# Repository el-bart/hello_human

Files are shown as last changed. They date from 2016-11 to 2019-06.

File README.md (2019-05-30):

# hello human

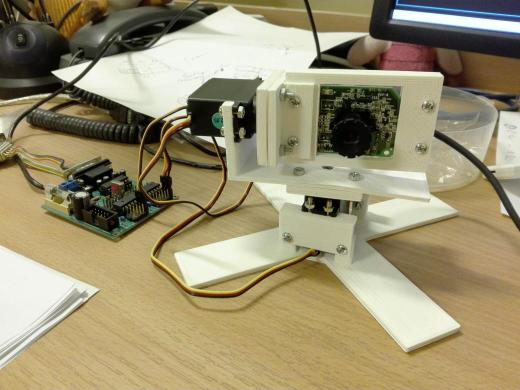
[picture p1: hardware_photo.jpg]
hardware construct


small hackaton to show ppl what programming is... doing stuff in real life. :)
it's more about the end effect than the code (quality) itself.

project is about making a 3d-printed box for usb-cam, that tracks faces it sees.

project is a mixture of Python and OpenSCAD code.

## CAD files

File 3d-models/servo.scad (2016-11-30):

use <servoMountLock.scad>

module servo()
{
  cube([40, 20, 36]);
  // mount shelf
  difference()
  {
    translate([-13/2, 0, 26])
      cube([53, 20, 3]);
    // holes
    #for(dx=[-1, +1])
      for(dy=[-1, +1])
        translate([53/2-13/2+dx*47/2, 20/2+dy*(6-1), 26-4])
          cylinder(r=4/2, $fs=1, h=10);
  }
  // rotor bottom
  translate([13/2+3.5, 20/2, 36])
  {
    cylinder(r=13/2, h=2);
    // rotor itself
    translate([0,0,2])
    {
      cylinder(r=9/2, h=2.5);
      // center part
      translate([-10/2, -10/2, 2.5])
      {
        cube([10, 10, 3.2]);
        // side bars
        translate([-10, (10-7.2)/2, 1.2])
          cube([30, 7.2, 2]);
      }
    }
  }
}

servo();

%translate([13/2+3.5, 20/2, 36+3.2-0.5])
  rotate([0, 0, 90])
    servoMountLock();

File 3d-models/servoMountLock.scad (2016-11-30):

module servoMountLock()
{
  space=[0.5, 0.5, 0.5];
  difference()
  {
    translate([-14-5, -10-10, 0])
      cube([2*(14+5), 2*(10+10), 4.5]);
    // screw holes
    for(dx = [-1, +1])
      for(dy = [-1, +1])
        translate([dx*14, dy*10, -2])
          cylinder(r=(3+1)/2, $fs=1.5, h=4.5+4);
    translate([0, 0, 1])
    {
      // main rod mounting hole
      translate([-(7.5+space[0])/2, -(30+space[1])/2, 4.5-(2+space[2])])
        cube([7.5, 30, 2] + space);
      // center, thicker part
      translate([-(10+space[0])/2, -(10+space[1])/2, 4.5-(3.5+space[2])])
        cube([10, 10, 3.5] + space);
    }
    // servo's screw space
    translate([0, 0, -1])
      cylinder(r=(9+1)/2, h=6, $fs=1);
  }
}

for(i=[0:1])
  translate([0, i*45, 0])
    servoMountLock();

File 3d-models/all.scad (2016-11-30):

use <bottomMount.scad>
use <servoMountLock.scad>
use <tiltMountBase.scad>
use <cameraFrame.scad>

use <servo.scad>
use <cammera.scad>


for(dy=[0,45])
  translate([0, dy, 0])
    servoMountLock();

translate([0, -45, 0])
  tiltMountBase();

translate([-73, -52, 0])
  rotate([0, 0, 180])
    bottomMount();

for(dy=[0, 50])
  translate([-95, -30+dy, 0])
    cameraFrame();


%translate([0, 100, 0])
{
  bottomMount();

  translate([-71, -13.5, 21])
  {
    rotate([0,90,0])
      rotate([0,0,90])
      {
        servo();
        translate([13/2+3.5, 20/2, 36+3.2-0.5])
          rotate([0, 0, 90])
            servoMountLock();
      }
    translate([50, 10, -7])
    {
      translate([13, 0, 0])
        cammera();
      translate([-1, 2, -6])
        rotate([90, 0, 0])
          cameraFrame();
      translate([70-1, -5, -6])
        rotate([90, 0, 180])
          cameraFrame();
    }
    translate([44, 10, 10])
      rotate([0, 90, 0])
        tiltMountBase();
  }

  translate([10, -10, -44])
    rotate([0,0,90])
    {
      servo();
      translate([13/2+3.5, 20/2, 36+3.2-0.5])
        rotate([0, 0, 90])
          servoMountLock();
    }
}

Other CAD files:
3d-models/base.scad
3d-models/bottomMount.scad
3d-models/cameraFrame.scad
3d-models/cammera.scad
3d-models/tiltMountBase.scad

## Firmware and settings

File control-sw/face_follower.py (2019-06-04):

#!/usr/bin/env python
import sys
import cv2
import time
import getopt
import Servo
import Tracker


def parseCmdLine():
    opts, args = getopt.getopt(sys.argv[1:], "hpns:v:", ["help", "preview", "no-preview", "serial=", "video="])
    if len(args) > 0:
        raise Exception("unknown argument: '" + args[0] + "'")
    preview = None
    serialDevice = None
    videoDevice = None
    for opt, arg in opts:
        if opt == "-h" or opt == "--help":
            sys.stdout.write(sys.argv[0] + " --video /dev/videoX --serial /dev/ttyUSBY {--help|--preview|--no-preview}\n")
            sys.exit(0)
        if opt == "-p" or opt == "--preview":
            preview = True
            continue
        if opt == "-n" or opt == "--no-preview":
            preview = False
            continue
        if opt == "-s" or opt == "--serial":
            serialDevice = arg
            continue
        if opt == "-v" or opt == "--video":
            videoDevice = arg
            continue
    if preview is None:
        raise Exception("preview must be explicitly enabled or disabled")
    if serialDevice is None:
        raise Exception("serial device name must be xplicitly provided")
    if videoDevice is None:
        raise Exception("video device name must be xplicitly provided")
    return preview, serialDevice, videoDevice


def drawRectangles(faces, img):
    for (x,y,w,h) in faces:
        cv2.rectangle(img, (x,y), (x+w,y+h), (0,0xff,0), 6)

def imageCenter(img):
    h,w,channels = img.shape
    return (w/2, h/2)

previewWindow, serialDevice, videoDevice = parseCmdLine()

lineDrv = Servo.LineDriver(serialDevice)
position = Servo.Position(lineDrv, 'l', 'f')
tracker = Tracker.Tracker(position)
fullscreen = False


faceDetector = cv2.CascadeClassifier('haarcascade_frontalface_default.xml')
frameGrabber = cv2.VideoCapture( int(videoDevice[-1]) )

if previewWindow:
    if fullscreen:
        cv2.namedWindow("preview", cv2.WND_PROP_FULLSCREEN)
        cv2.setWindowProperty("preview", cv2.WND_PROP_FULLSCREEN, cv2.cv.CV_WINDOW_FULLSCREEN)
    else:
        cv2.namedWindow("preview", cv2.WINDOW_NORMAL)

ret    = 0
errors = 0
frameCount = 0
lastFpsPrint = time.time();

while True:
    try:
        frameCount += 1
        if frameCount > 20:
            now = time.time()
            timeElapsed = now - lastFpsPrint
            sys.stderr.write('\nFPS=' + str(frameCount / float(timeElapsed)) + '\n')
            frameCount = 0
            lastFpsPrint = now

        if cv2.waitKey(1) & 0xFF == ord('q'):
            break

        ret, img = frameGrabber.read()
        gray     = cv2.cvtColor(img, cv2.COLOR_BGR2GRAY)
        center   = imageCenter(img)
        faces    = faceDetector.detectMultiScale(gray, 1.3, 5)
        if previewWindow:
            drawRectangles(faces, img)
            cv2.imshow("preview",img)

        tracker.updatePositionForFaces(faces, center)
        sys.stderr.write('#')
        errors = 0

    except Exception as ex:
        errors += 1
        sys.stderr.write('!')
        sys.stderr.write( "\n" + sys.argv[0] + ": ERROR: " + str(ex) + "\n" )
        if errors > 20:
            sys.stderr.write("\n" + sys.argv[0] + ": TOO MANY ERRORS IN A ROW - SHUTTING DOWN...\n")
            ret = 42
            break

sys.stderr.write('\n')
frameGrabber.release()
cv2.destroyAllWindows()
sys.exit(ret)

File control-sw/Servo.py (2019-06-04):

#!/usr/bin/env python
import time
import serial


class LineDriver:
    def __init__(self, dev, timeout = 0.050):
        self._io = serial.Serial(port=dev, baudrate=38400, timeout=0)
        if not self._io.isOpen():
            raise Expception("cannot open serial port: " + dev)
        self._timeout = timeout

    def sendCmd(self, cmd):
        self._io.write(cmd + "\n")

    def readResponse(self):
        return self.__readLine()

    def __readLine(self):
        deadline = time.time() + self._timeout
        line = ''
        while time.time() <= deadline:
            c = self._io.read(1)
            if c == '\r' or c == '\n':
                return line
            line += c
        raise Exception("timeout whilre reading from serial port")


# set [-1; +1] range to servo position
class Position:
    def __init__(self, line, panLine, tiltLine):
        self._line     = line
        self._panLine  = panLine
        self._tiltLine = tiltLine


    def set(self, pan, tilt):
        self.__set(self._panLine, pan)
        self.__set(self._tiltLine, tilt)

    def __set(self, axis, value):
        cmd = axis + 's' + self.__value2hex(value)
        cmd = cmd + self.__checksum2str( self.__checksum(cmd) )
        self._line.sendCmd(cmd)
        resp = self._line.readResponse()
        if resp != axis + "-ok":
            raise Exception("error response from servo controler: " + resp)

    def __checksum(self, cmd):
        out = 0x00
        for c in cmd:
            out ^= ord(c)
        lb = out & 0x0f
        hb = (out & 0xf0) >> 4
        return lb^hb

    def __checksum2str(self, cs):
        return "%x" % int(cs)

    def __value2hex(self, value):
        if value < -1.0 or 1.0 < value:
            raise Exception("value '" + str(value) + "' out of [-1; +1] range")
        norm = (value+1.0)/2 * 255;
        i    = int( round(norm, 0) )
        return "%0.2x" % i

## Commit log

2016-11-27 servo controller module
2016-11-27 added servo controller to the main app (not used yet, though)
2016-11-28 servo motor model
    [servo.scad]
2016-11-28 base mount - base model
    [bottomMount.scad]
2016-11-28 added base servo to visualtization too
    [bottomMount.scad]
2016-11-30 comment added
    [bottomMount.scad]
2016-11-30 mount pad for servo motors
    [servoMountLock.scad]
2016-11-30 added servo mount pad, for visualization purposes
    [bottomMount.scad, servo.scad]
2016-11-30 fixed $fs parameter
    [servoMountLock.scad]
2016-11-30 cammera visualization added
    [bottomMount.scad, cammera.scad]
2016-11-30 added missing comment
    [servoMountLock.scad]
2016-11-30 tilt mount base added
    [tiltMountBase.scad]
2016-11-30 added tilt mount base to the visualization
    [bottomMount.scad]
2016-11-30 camera frame elements added
    [cameraFrame.scad]
2016-11-30 added camera frame to the visualization
    [bottomMount.scad]
2016-11-30 whole cut-in for rod shifted 1mm up, so that it does stand out, so it can be screwed solid
    [servoMountLock.scad]
2016-11-30 space is now smaller, so that rod fits in tight
    [servoMountLock.scad]
2016-11-30 updated positioning of servo mount lock to new dimentions
    [bottomMount.scad, servo.scad, tiltMountBase.scad]
2016-11-30 common file, to provide all the elements on a single print
    [all.scad]
2016-11-30 all elements on one print
    [all.scad]
2016-11-30 visualization moved to all.scad file
    [all.scad, bottomMount.scad]
2016-12-01 base element added
    [base.scad]
2016-12-01 servo test app
2016-12-01 base module reorganized so that it prints nicely and have space for servo cables
    [base.scad]
2016-12-01 image center is now computed correctly
    [face_follower.py]
2016-12-01 skipping servo mechanics corrections, if the position is already centerd properly
    [Tracker.py]
2016-12-01 draft of the implementation for in-image to servo offset position calculator
2016-12-01 no need to get exact error traceback
    [face_follower.py]
2016-12-01 fixed tilt orientation and limits; fine tuned starting position and inactivity period
    [Tracker.py]
2016-12-01 pan normalization verified; removed most test prints; pan settings are saved only uppon successful command execution
2016-12-01 removed debug prints
2016-12-01 AVR-servo project copy (v2.0.2)
2016-12-01 getting back to default position resets face timeout, to limit dummy commands sending
    [Tracker.py]
2016-12-03 servo board schematics (v2.0.2 too)
    [avr_servo.brd, avr_servo.sch]
2016-12-03 directories naming unified
    [all.scad, avr_servo.brd, avr_servo.sch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]
2019-06-04 moved back to old bindings, on docker image
    [face_follower.py]
2019-06-04 added FPS print every once in a while
2019-06-04 each error is now explicitly printer on a console
    [face_follower.py]
2019-06-04 decreased move-per-pixel constant and added 3 retries for each failed I/O
    [Tracker.py]
2019-06-04 docker image tag is now auto-selected based on current revision/tag
2019-06-04 video and serial port devices are now paramters
2019-06-04 video and seral devices are now explicit, required paramters for the tool
